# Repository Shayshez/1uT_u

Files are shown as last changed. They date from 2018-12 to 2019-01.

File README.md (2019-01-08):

# 1uT_u
1u Version (Pulp Logic) of Temps Utile, 30HP.

For pcb's and panels: https://pushermanproductions.com/product/plum-audio-1u-temps-utile-pcb-and-aluminium-panel-30hp/

Teensy Assembling (with Supervisor):https://youtu.be/IDsQhNgkL-Y

OLED Screen Assembling: https://youtu.be/ywh_6SPNrSg 

** Note for Pusherman v1.0 Pcb's - There is minor silk screen mistake - The Inputs and Outputs not numberd correctly.
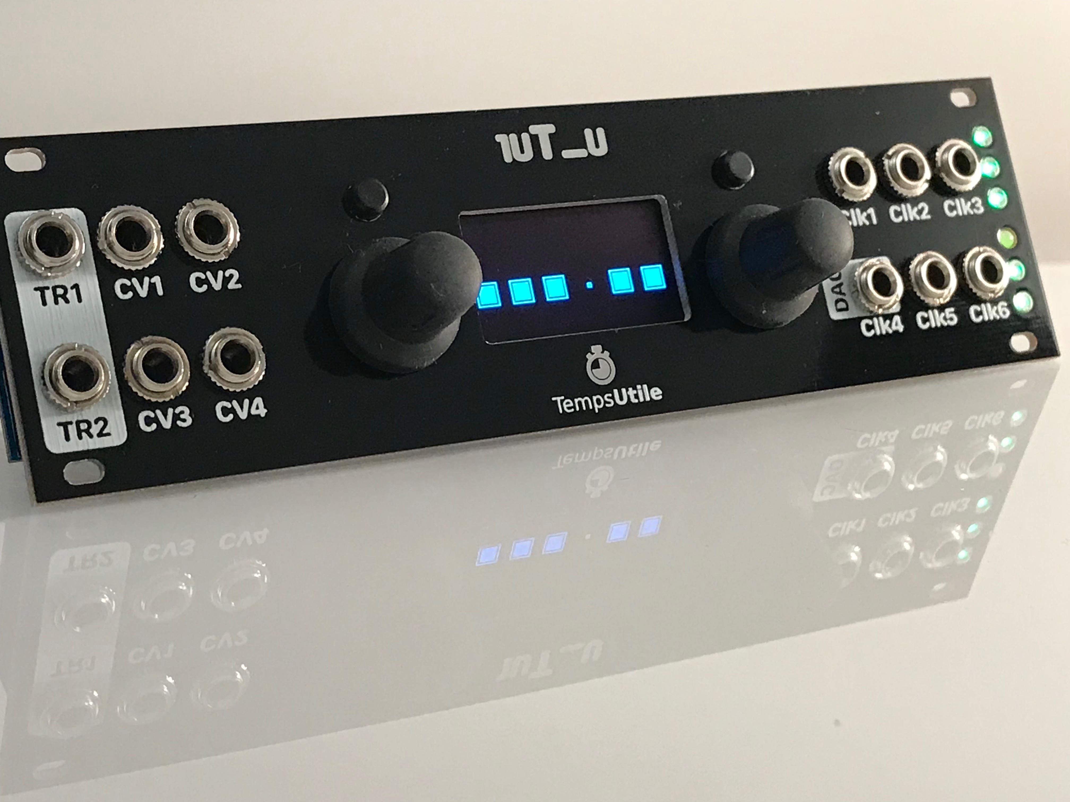
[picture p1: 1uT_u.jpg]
1uT_u


1uT_u

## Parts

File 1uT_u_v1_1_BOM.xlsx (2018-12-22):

Qty | Value | Device | Package |  | Parts | Description | ALLIED_NUMBER | ALLIED_PRICE-STOCK | ARROW_PART_NUMBER | ARROW_PRICE-STOCK | AVAILABILITY | DESCRIPTION | HEIGHT | MANUFACTURER_NAME | MANUFACTURER_PART_NUMBER | MF | MP | MPN | OC_FARNELL | OC_NEWARK | PACKAGE | PRICE | RS_PART_NUMBER | RS_PRICE-STOCK | SPICEPREFIX | WE-NUMBER
4 | 100R | R-EU_R0603 | R0603 | 603-RC0603FR-07100RL | R34, R36, R41, R42 | RESISTOR, European symbol |  |  |  |  |  |  |  |  |  |  |  |  |  |  |  |  |  |  | R
3 | 510R | R-EU_R0603 | R0603 | 603-RC0603FR-07510RL | R29, R31, R32 | RESISTOR, European symbol |  |  |  |  |  |  |  |  |  |  |  |  |  |  |  |  |  |  | R
7 | 1.0k | R-EU_R0603 | R0603 | 603-RC0603FR-071KL | R7, R9, R12, R15, R17, R24, R27 | RESISTOR, European symbol |  |  |  |  |  |  |  |  |  |  |  |  |  |  |  |  |  |  | R
1 | 1k2 | R-EU_R0603 | R0603 | 603-RC0603FR-101K2L | R18 | RESISTOR, European symbol |  |  |  |  |  |  |  |  |  |  |  |  |  |  |  |  |  |  | R
1 | 1k8 | R-EU_R0603 | R0603 | 603-RC0603FR-071K8L | R16 | RESISTOR, European symbol |  |  |  |  |  |  |  |  |  |  |  |  |  |  |  |  |  |  | R
1 | 2K | R-EU_R0603 | R0603 | 603-RC0603FR-102KL | R33 | RESISTOR, European symbol |  |  |  |  |  |  |  |  |  |  |  |  |  |  |  |  |  |  | R
2 | 3k | R-EU_R0603 | R0603 | 603-RC0603FR-073KL | R21, R22 | RESISTOR, European symbol |  |  |  |  |  |  |  |  |  |  |  |  |  |  |  |  |  |  | R
1 | 3k9 | R-EU_R0603 | R0603 | 603-RC0603FR-133K9L | R30 | RESISTOR, European symbol |  |  |  |  |  |  |  |  |  |  |  |  |  |  |  |  |  |  | R
1 | 4k2 | R-EU_R0603 | R0603 | 603-RC0603FR-074K22L | R28 | RESISTOR, European symbol |  |  |  |  |  |  |  |  |  |  |  |  |  |  |  |  |  |  | R
1 | 6k8 | R-EU_R0603 | R0603 | 603-RC0603FR-106K8L | R20 | RESISTOR, European symbol |  |  |  |  |  |  |  |  |  |  |  |  |  |  |  |  |  |  | R
5 | 10k | R-EU_R0603 | R0603 | 603-RC0603FR-0710KL | R6, R11, R14, R23, R25 | RESISTOR, European symbol |  |  |  |  |  |  |  |  |  |  |  |  |  |  |  |  |  |  | R
5 | 20k | R-EU_R0603 | R0603 | 603-RC0603FR-1020KL | R8, R10, R13, R19, R26 | RESISTOR, European symbol |  |  |  |  |  |  |  |  |  |  |  |  |  |  |  |  |  |  | R
6 | 33k | R-EU_R0603 | R0603 | 603-RC0603FR-0733KL | R39, R40, R43, R48, R51, R52 | RESISTOR, European symbol |  |  |  |  |  |  |  |  |  |  |  |  |  |  |  |  |  |  | R
2 | 47k | R-EU_R0603 | R0603 | 603-RC0603FR-0747KL | R54, R55 | RESISTOR, European symbol |  |  |  |  |  |  |  |  |  |  |  |  |  |  |  |  |  |  | R
4 | 75k | R-EU_R0603 | R0603 | 603-AC0603FR-0775KL | R37, R45, R46, R49 | RESISTOR, European symbol |  |  |  |  |  |  |  |  |  |  |  |  |  |  |  |  |  |  | R
11 | 100k | R-EU_R0603 | R0603 | 603-RC0603FR-07100KL | R1, R2, R3, R4, R5, R35, R38, R44, R47, R50, R53 | RESISTOR, European symbol |  |  |  |  |  |  |  |  |  |  |  |  |  |  |  |  |  |  | R
4 | 330p-560p | C-EUC0603 C0G/NP0 | C0603 | 77-VJ0603A561GXACBC | C27, C30, C31, C32 | CAPACITOR, European symbol
2 | 1n | C-EUC0603 | C0603 | 80-C0603C102K5REC (https://www.mouser.co.il/ProductDetail/KEMET/C0603C102K5RECTU) | C8, C9 | CAPACITOR, European symbol
2 | 3.3n | C-EUC0603 | C0603 | 80-C0603C332K5REC (https://www.mouser.co.il/ProductDetail/KEMET/C0603C332K5RECTU) | C7, C13 | CAPACITOR, European symbol
14 | 100n | C-EUC0603 | C0603 | 80-C0603C104K3NAUTO (https://www.mouser.co.il/ProductDetail/KEMET/C0603C104K3NACAUTO) | C3, C4, C5, C6, C10, C11, C14, C17, C22, C23, C26, C28, C29, C33 | CAPACITOR, European symbol
3 | 470n | C-EUC0603 | C0603 | 810-CGA3E3X7R1H474KB (https://www.mouser.co.il/ProductDetail/TDK/CGA3E3X7R1H474K080AB) | C15, C18, C19 | CAPACITOR, European symbol
2 | 1uF | C-EUC0603 | C0603 | 603-CC603KRX5R8BB105 (https://www.mouser.co.il/ProductDetail/Yageo/CC0603KRX5R8BB105) | C24, C25 | CAPACITOR, European symbol
2 | 10uF | C-EUC1206K | C1206K | 963-TMK316BJ106ML-T (https://www.mouser.co.il/ProductDetail/963-TMK316BJ106ML-T) | C20, C21 | CAPACITOR, European symbol
2 | 10uF | CPOL-EUB | PANASONIC_B | 667-EEE-FK1H100SR (https://www.mouser.co.il/ProductDetail/Panasonic/EEE-FK1H100SR) | C1, C2 | POLARIZED CAPACITOR, European symbol |  |  |  |  |  |  |  |  |  |  |  |  |  |  |  |  |  |  | C
2 | 22uF | CPOL-EUC | PANASONIC_C | 667-EEE-FK1H220SR (https://www.mouser.co.il/ProductDetail/Panasonic/EEE-FK1H220SR) | C12, C16 | POLARIZED CAPACITOR, European symbol |  |  |  |  |  |  |  |  |  |  |  |  |  |  |  |  |  |  | C
2 | 1N5819HW | DIODE_DIODE-SOD123 | DIODE_SOD123 | 621-1N5819HW-F (https://www.mouser.co.il/ProductDetail/Diodes-Incorporated/1N5819HW-7-F) | D1, D2 | DIODE
1 | 10uH | WE-LQ_1210_744032001 | WE-LQ_M | 963-LB3218T100K (https://www.mouser.com/Search/ProductDetail.aspx) | L1 | SMD Inductor |  |  |  |  |  |  |  |  |  |  |  |  |  |  |  |  |  |  |  | 744032001/1uH
1 | LM4040-5V | LM4041B12DBZ | DBZ_R-PDSO-G3 | 926-LM4040DIM350NOPB (https://www.mouser.co.il/ProductDetail/Texas-Instruments/LM4040DIM3-50-NOPB) | IC5 | PRECISION MICROPOWER SHUNT VOLTAGE REFERENCE |  |  |  |  |  |  |  |  |  |  |  | LM4041B12IDBZR | 1575212 | 58K5882
2 | TL072D | TL072D | SO08 | 595-TL072CDR (https://www.mouser.co.il/ProductDetail/Texas-Instruments/TL072CDR?qs=sGAEpiMZZMtYFXwiBRPs0zzUsTTH4TUq) | IC1, IC2 | OP AMP
1 | TL074D | TL074D | SO14 | 595-TL074CDR (https://www.mouser.co.il/ProductDetail/Texas-Instruments/TL074CDR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) | IC3 | OP AMP
2 | MCP6002SMT | MCP6002SMT | SOIC8 | 579-MCP6002T-I/SN (https://www.mouser.co.il/ProductDetail/Microchip-Technology/MCP6002T-I-SN?qs=sGAEpiMZZMsUzhEcHltCuY6YBL510a4u) | IC6, IC7 | Dual General Op Amp
1 | LD1117S50TR | LD1117S50TR | SOT223 | 511-LD1117S50 | U2 | http://octopart.com/ld1117s50tr-stmicroelectronics-529395 |  |  |  |  | Good | LD1117 Series 1300 mA 5 V Fixed Output Positive Voltage LDO Regulator - SOT-223 |  |  |  | STMicroelectronics | LD1117S50TR |  |  |  | SOT-223 STMicroelectronics | 0.19 USD
2 | MMBT3904LT1G | TRANSISTOR_MMBT3904LT1-NPN-SOT23-BEC | TRANSISTOR_SOT23-BEC | 863-MMBT3904LT1G (https://www.mouser.co.il/ProductDetail/ON-Semiconductor/MMBT3904LT1G) | Q1, Q2 | NPN Transistror
1 | MIC803-46D2VM3TR | MIC803-46D2VM3TR | SEE DESCRIPOTION -->> | 998-MIC803-26D2VM3TR (https://www.mouser.co.il/ProductDetail/998-MIC803-26D2VM3TR) | IC4 | Teensy Supervisor, You need this only if your case used Linear PSU, Use TH resistor leg to connect RESET hole on 1uT_u PCB to RESET pad on the teensy. In this case it's better to solder the teensy directly to the board. |  |  |  |  |  | 3-pin Microprocessor Supervosor Circui | mm | Micrel | MIC803-46D2VM3TR
1 | ADP150AUJZ-3.3-R7 | ADP150AUJZ-3.3-R7 | SOT95P280X100-5N | 584-ADP150AUJZ-3.3R7 | U1 | IC REG LINEAR 2V 150MA 5TSOT |  |  |  |  | Good | LDO Regulator Pos 2V 0.15A 5-Pin TSOT T/R |  |  |  | Analog Devices | ADP150AUJZ-2.0-R7 |  |  |  | TSOT-23 Analog Devices | 0.65 USD
2 | Tact Switch | TACT_SWITCHPTH | TACTILE-PTH | 612-TL1105SP-250 (https://www.mouser.co.il/ProductDetail/612-TL1105SP-250) | SW1, SW2 | Momentary Switch
2 | Tact Switch caps |  |  | 12-1R-BK (https://www.mouser.co.il/ProductDetail/612-1R-BK) | SW1, SW2 | For more colours: https://www.mouser.com/Search/Refine.aspx?FS=TRUE
2 | PEC11R | PEC11R | PEC11R-4XXXK-SXXXX | 858-EN11-HSM1BF20 (https://www.mouser.co.il/ProductDetail/858-EN11-HSM1BF20) | ENC-L, ENC-R | Incremental encoder 24 detents 24 pulses Bourns 24 Pulse Incremental Mechanical Rotary Encoder with a 6 mm Flat Shaft (Not Indexed), Through Hole | 70407906 | https://www.alliedelec.com/bourns-pec11r-4215k-s0024/70407906/ | PEC11R-4215K-S0024 | http://uk.rs-online.com/web/p/products/1674651 |  | Incremental encoder 24 detents 24 pulses Bourns 24 Pulse Incremental Mechanical Rotary Encoder with a 6 mm Flat Shaft (Not Indexed), Through Hole | mm | Bourns | PEC11R-4215K-S0024 |  |  |  |  |  |  |  | 1674651 | http://uk.rs-online.com/web/p/products/1674651
2 | Knobs | Sifam soft touch Encoder Knob |  |  |  | https://www.thonk.co.uk/shop/sifam-soft-touch-encoder-knobs/
1 | TEENSY_3.2 | TEENSY_3.2 | TEENSY_3.2 | Osh Park | TEENSY_3.2 | https://store.oshpark.com/products/teensy-3-1
1 | OLED | 1U_1.3_OLED_2 | 1U_1.3_OLED_2 | See GitHub link -->> | OLED | https://github.com/Shayshez/1_3_OLED_FOR_1U
1 | 1X40 Pin Header | Theensy / OLED connector
1 | 2X5 Pin Header | POWER | POWER_10 |  | J1
5 | LED | LED3MM | LED3MM |  | LED1, LED2, LED3, LED5, LED6 | https://www.ebay.com/itm/100pcs-5mm-Red-Yellow-Blue-Green-White-Flat-Top-LED-Wide-Angle-Leds-Resistors-/221503673632
1 | LED BI COLOUR (RED/GREEN) | LED3MM | LED3MM | WP937EGW | LED4 | LED BI BOLOUR
12 | PJ301_THONKICONN | THONKICONN | WQP_PJ_301M6 | Thonk | CL1, CL2, CL3, CL4, CL4/DAC, CL5, CV_1, CV_2, CV_3, CV_4, TRIG1, TRIG2 | THONKICONN
3 | 3M/6MM Nylon standoffs | For screen mounting |  |  |  | https://www.aliexpress.com/item/100pcs-lot-M3-5-6-8-10-12-15-18-20-25-black-Nylon-standoff-3mm/32874390664.html
5 | 3M Nylon screws | For screen mounting |  |  |  | https://www.aliexpress.com/item/Black-100Pcs-Lot-Plastic-Nylon-M3-Hex-Column-Standoff-Spacer-Phillips-Screw-New/32747099724.html

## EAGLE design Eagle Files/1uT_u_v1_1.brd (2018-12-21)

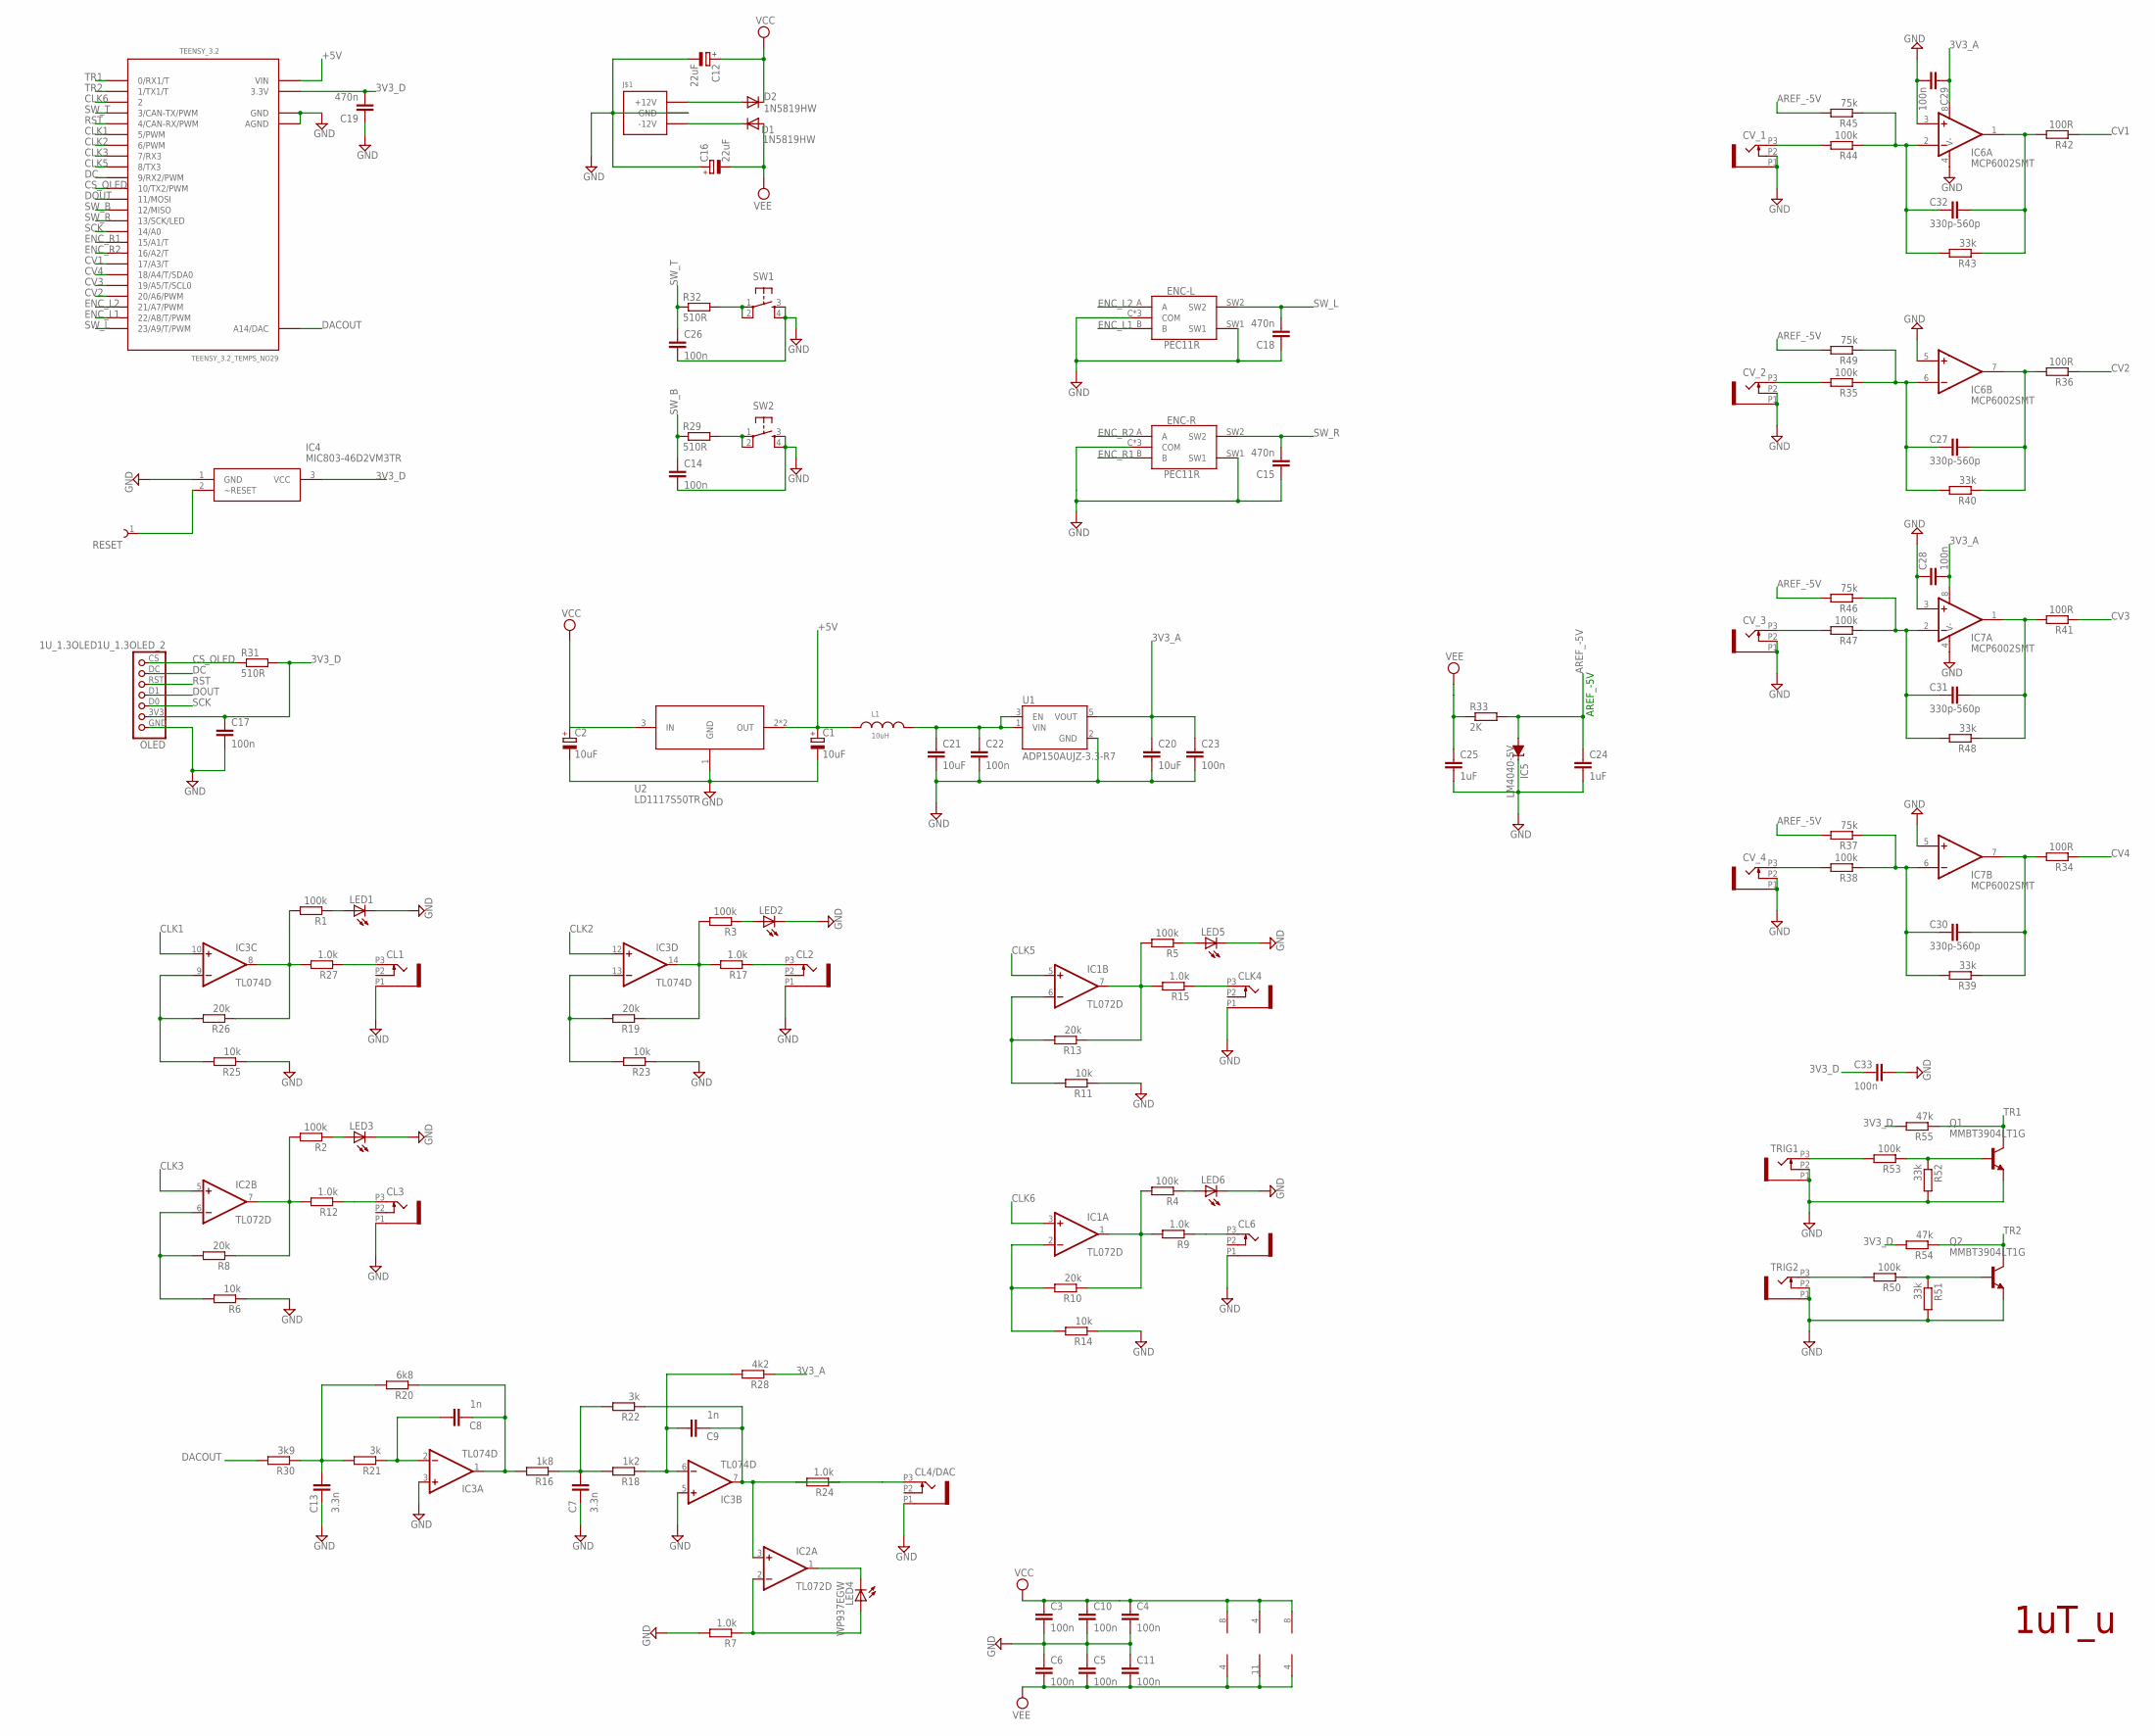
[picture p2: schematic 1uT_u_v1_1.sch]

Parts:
C1, C2: 10uF; PANASONIC_B
C3, C4, C5, C6, C10, C11, C14, C17, C22, C23, C26, C28, C29, C33: 100n; C0603
C7, C13: 3.3n; C0603
C8, C9: 1n; C0603
C12, C16: 22uF; PANASONIC_C
C15, C18, C19: 470n; C0603
C20, C21: 10uF; C1206K
C24, C25: 1uF; C0603
C27, C30, C31, C32: 330p-560p; C0603
CL1, CL2, CL3, CL4/DAC, CL6: OG-PJ301_PJ301_THONKICONN; OG-PJ301_WQP_PJ_301M6_NO_HOLE
CLK4: OG-PJ301_PJ301_THONKICONN; OG-PJ301_WQP_PJ_301M6_NO_HOLE
CV_1, CV_2, CV_3, CV_4: OG-PJ301_PJ301_THONKICONN; OG-PJ301_WQP_PJ_301M6_NO_HOLE
D1, D2: 1N5819HW; DIODE_SOD123
ENC-L: PEC11R; PEC11R-4XXXK-SXXXX
ENC-R: PEC11R; PEC11R-4XXXK-SXXXX
IC1, IC2: TL072D; SO08
IC3: TL074D; SO14
IC4: MIC803-46D2VM3TR; SOT95P230X110-3N
IC5: LM4040-5V; DBZ_R-PDSO-G3
IC6, IC7: MCP6002SMT; SOIC8
J$1: POWER_SIMPLE10; POWER_10
L1: 10uH; WE-LQ_M
LED1, LED2, LED3, LED5, LED6: LED3MM
LED4: WP937EGW; LED3MM
OLED: 1U_1.3OLED1U_1.3OLED_2; 1U_1.3OLED_2
Q1, Q2: MMBT3904LT1G; TRANSISTOR_SOT23-BEC
R1, R2, R3, R4, R5, R35, R38, R44, R47, R50, R53: 100k; R0603
R6, R11, R14, R23, R25: 10k; R0603
R7, R9, R12, R15, R17, R24, R27: 1.0k; R0603
R8, R10, R13, R19, R26: 20k; R0603
R16: 1k8; R0603
R18: 1k2; R0603
R20: 6k8; R0603
R21, R22: 3k; R0603
R28: 4k2; R0603
R29, R31, R32: 510R; R0603
R30: 3k9; R0603
R33: 2K; R0603
R34, R36, R41, R42: 100R; R0603
R37, R45, R46, R49: 75k; R0603
R39, R40, R43, R48, R51, R52: 33k; R0603
R54, R55: 47k; R0603
RESET: 61300111121
SW1, SW2: TAC_SWITCHPTH; TACTILE-PTH
TEENSY_3.2: TEENSY_3.2_TEMPS_NO29
TRIG1, TRIG2: OG-PJ301_PJ301_THONKICONN; OG-PJ301_WQP_PJ_301M6_NO_HOLE
U1: ADP150AUJZ-3.3-R7; SOT95P280X100-5N
U2: LD1117S50TR; SOT223

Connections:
3V3_A: C20.1, C23.1, C28.2, C29.1, IC6.8 (V+), IC7.8 (V+), R28.1, U1.5 (VOUT)
3V3_D: C17.1, C19.2, C33.2, IC4.3 (VCC), OLED.3V3, R31.2, R54.2, R55.2, TEENSY_3.2.3.3V
+5V: C1.+, L1.1, TEENSY_3.2.VIN, U2.2 (OUT), U2.4 (OUT)
AREF_-5V: C24.1, IC5.2 (A), R33.2, R37.2, R45.2, R46.2, R49.2
CLK1: IC3.10 (+IN), TEENSY_3.2.5 (5/PWM)
CLK2: IC3.12 (+IN), TEENSY_3.2.6 (6/PWM)
CLK3: IC2.5 (+IN), TEENSY_3.2.7 (7/RX3)
CLK5: IC1.5 (+IN), TEENSY_3.2.8 (8/TX3)
CLK6: IC1.3 (+IN), TEENSY_3.2.2
CS_OLED: OLED.CS, R31.1, TEENSY_3.2.10 (10/TX2/PWM)
CV1: R42.1, TEENSY_3.2.17/A3 (17/A3/T)
CV2: R36.1, TEENSY_3.2.20/A6 (20/A6/PWM)
CV3: R41.1, TEENSY_3.2.19/A5 (19/A5/T/SCL0)
CV4: R34.1, TEENSY_3.2.18/A4 (18/A4/T/SDA0)
DACOUT: R30.2, TEENSY_3.2.RESET/DAC (A14/DAC)
DC: OLED.DC, TEENSY_3.2.9 (9/RX2/PWM)
DOUT: OLED.D1, TEENSY_3.2.11 (11/MOSI)
ENC_L1: ENC-L.B, TEENSY_3.2.22/A8 (22/A8/T/PWM)
ENC_L2: ENC-L.A, TEENSY_3.2.21/A7 (21/A7/PWM)
ENC_R1: ENC-R.B, TEENSY_3.2.15/A1 (15/A1/T)
ENC_R2: ENC-R.A, TEENSY_3.2.16/A2 (16/A2/T)
GND: C1.-, C2.-, C3.2, C4.2, C5.1, C6.1, C7.2, C10.2, C11.1, C12.-, C13.2, C14.2, C15.1, C16.+, C17.2, C18.1, C19.1, C20.2, C21.2, C22.2, C23.2, C24.2, C25.2, C26.2, C28.1, C29.2, C33.1, CL1.P1 (1), CL2.P1 (1), CL3.P1 (1), CL4/DAC.P1 (1), CL6.P1 (1), CLK4.P1 (1), CV_1.P1 (1), CV_1.P2 (2), CV_2.P1 (1), CV_2.P2 (2), CV_3.P1 (1), CV_3.P2 (2), CV_4.P1 (1), CV_4.P2 (2), ENC-L.C (COM), ENC-L.SH1 (COM), ENC-L.SH2 (COM), ENC-L.SW1, ENC-R.C (COM), ENC-R.SH1 (COM), ENC-R.SH2 (COM), ENC-R.SW1, IC3.3 (+IN), IC3.5 (+IN), IC4.1 (GND), IC5.1 (C), IC6.3 (+IN), IC6.4 (V-), IC6.5 (+IN), IC7.3 (+IN), IC7.4 (V-), IC7.5 (+IN), J$1.3 (GND), J$1.4 (GND), J$1.5 (GND), J$1.6 (GND), J$1.7 (GND), J$1.8 (GND), LED1.K (C), LED2.K (C), LED3.K (C), LED5.K (C), LED6.K (C), OLED.GND, Q1.E, Q2.E, R6.1, R7.2, R11.1, R14.1, R23.1, R25.1, R51.2, R52.2, SW1.3, SW1.4, SW2.3, SW2.4, TEENSY_3.2.AGND, TEENSY_3.2.GND, TRIG1.P1 (1), TRIG1.P2 (2), TRIG2.P1 (1), TRIG2.P2 (2), U1.2 (GND), U2.1 (GND)
unnamed: D2.A, J$1.9 (+12V), J$1.10 (+12V)
unnamed: C21.1, C22.1, L1.2, U1.1 (VIN), U1.3 (EN)
unnamed: CV_1.P3 (3), R44.2
unnamed: C32.2, IC6.2 (-IN), R43.2, R44.1, R45.1
unnamed: C32.1, IC6.1 (OUT), R42.2, R43.1
unnamed: R32.2, SW1.1, SW1.2
unnamed: CV_2.P3 (3), R35.2
unnamed: R29.2, SW2.1, SW2.2
unnamed: C27.2, IC6.6 (-IN), R35.1, R40.2, R49.1
unnamed: C27.1, IC6.7 (OUT), R36.2, R40.1
unnamed: CV_3.P3 (3), R47.2
unnamed: C31.2, IC7.2 (-IN), R46.1, R47.1, R48.2
unnamed: C31.1, IC7.1 (OUT), R41.2, R48.1
unnamed: CV_4.P3 (3), R38.2
unnamed: C30.2, IC7.6 (-IN), R37.1, R38.1, R39.2
unnamed: C30.1, IC7.7 (OUT), R34.2, R39.1
unnamed: R53.2, TRIG1.P3 (3)
unnamed: Q1.B, R52.1, R53.1
unnamed: R50.2, TRIG2.P3 (3)
unnamed: Q2.B, R50.1, R51.1
unnamed: CL1.P3 (3), R27.1
unnamed: CL3.P3 (3), R12.1
unnamed: IC1.6 (-IN), R11.2, R13.2
unnamed: IC1.7 (OUT), R5.2, R13.1, R15.2
unnamed: IC3.13 (-IN), R19.2, R23.2
unnamed: IC3.9 (-IN), R25.2, R26.2
unnamed: IC3.8 (OUT), R1.2, R26.1, R27.2
unnamed: CLK4.P3 (3), R15.1
unnamed: IC3.14 (OUT), R3.2, R17.2, R19.1
unnamed: CL2.P3 (3), R17.1
unnamed: IC2.6 (-IN), R6.2, R8.2
unnamed: IC2.7 (OUT), R2.2, R8.1, R12.2
unnamed: IC1.2 (-IN), R10.2, R14.2
unnamed: IC2.1 (OUT), LED4.K (C)
unnamed: IC2.2 (-IN), LED4.A, R7.1
unnamed: CL4/DAC.P3 (3), R24.1
unnamed: IC1.1 (OUT), R4.2, R9.2, R10.1
unnamed: CL6.P3 (3), R9.1
unnamed: C9.2, IC2.3 (+IN), IC3.7 (OUT), R22.1, R24.2
unnamed: D1.C, J$1.1 (-12V), J$1.2 (-12V)
unnamed: C13.1, R20.2, R21.2, R30.1
unnamed: C8.1, IC3.2 (-IN), R21.1
unnamed: C8.2, IC3.1 (OUT), R16.2, R20.1
unnamed: C7.1, R16.1, R18.2, R22.2
unnamed: C9.1, IC3.6 (-IN), R18.1, R28.2
unnamed: LED3.A, R2.1
unnamed: LED1.A, R1.1
unnamed: LED2.A, R3.1
unnamed: LED5.A, R5.1
unnamed: LED6.A, R4.1
unnamed: IC4.2 (~RESET), RESET.1
RST: OLED.RST, TEENSY_3.2.4 (4/CAN-RX/PWM)
SCK: OLED.D0, TEENSY_3.2.14/A0
SW_B: C14.1, R29.1, TEENSY_3.2.12 (12/MISO)
SW_L: C18.2, ENC-L.SW2, TEENSY_3.2.23/A9 (23/A9/T/PWM)
SW_R: C15.2, ENC-R.SW2, TEENSY_3.2.13 (13/SCK/LED)
SW_T: C26.1, R32.1, TEENSY_3.2.3 (3/CAN-TX/PWM)
TR1: Q1.C, R55.1, TEENSY_3.2.0 (0/RX1/T)
TR2: Q2.C, R54.1, TEENSY_3.2.1 (1/TX1/T)
VCC: C2.+, C3.1, C4.1, C10.1, C12.+, D2.C, IC1.8 (V+), IC2.8 (V+), IC3.4 (V+), U2.3 (IN)
VEE: C5.2, C6.2, C11.2, C16.-, C25.1, D1.A, IC1.4 (V-), IC2.4 (V-), IC3.11 (V-), R33.1

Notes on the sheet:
AREF_-5V
1uT_u

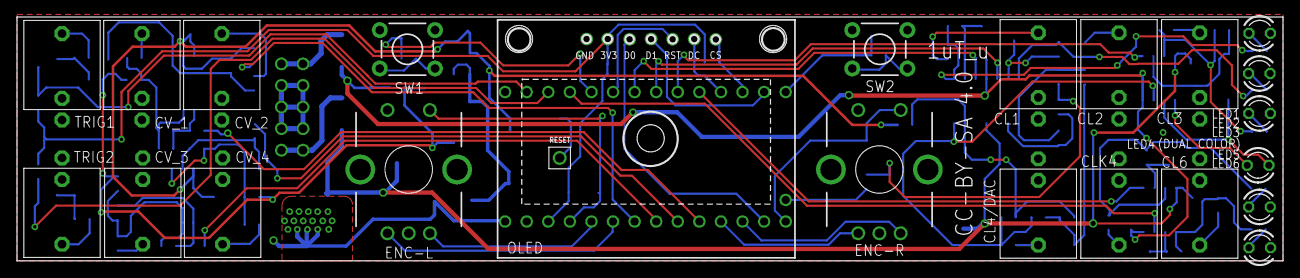
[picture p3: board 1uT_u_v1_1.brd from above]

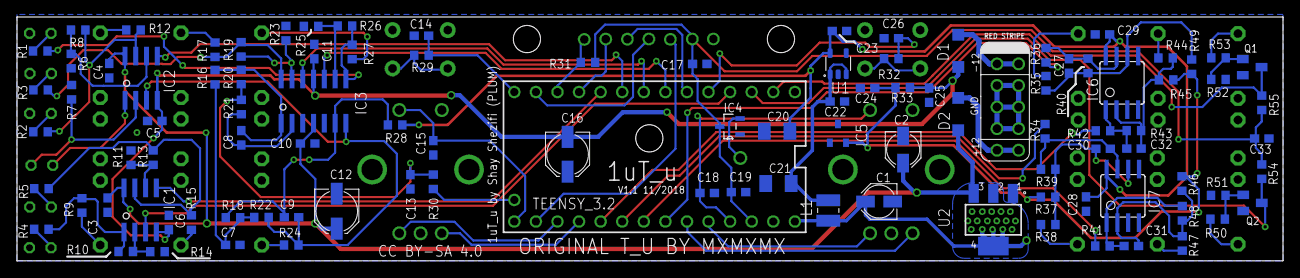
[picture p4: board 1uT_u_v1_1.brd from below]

Board: 2 copper layers, 149.0 x 28.7 mm, 128 parts (104 on the bottom side), 83 nets.

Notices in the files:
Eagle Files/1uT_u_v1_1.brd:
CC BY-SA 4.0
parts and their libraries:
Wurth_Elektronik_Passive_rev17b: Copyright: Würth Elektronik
